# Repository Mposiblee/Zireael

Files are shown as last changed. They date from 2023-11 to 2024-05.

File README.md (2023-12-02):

# Zireael keyboard

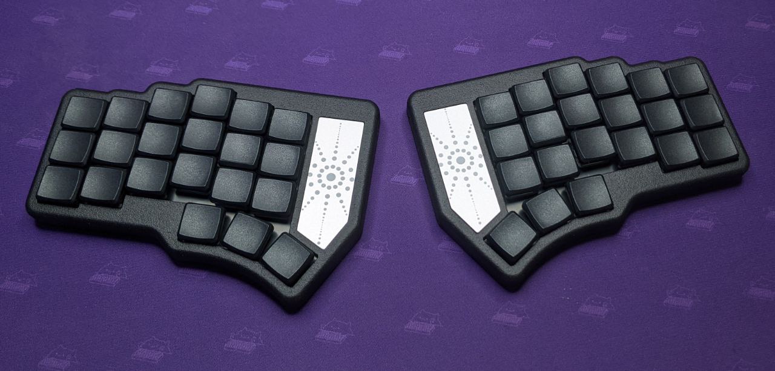
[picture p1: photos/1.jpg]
Dao Shield

Zireael is an ergonomic wireless split keyboard with a design bias. Keyboard for Kailh Choc switches based on MINEW MS88SF2 BLE module.

The keyboard is based on Dao Chok BLE. The locations of components on the board have been changed, space for the battery has been added, and the thumb cluster has also been changed.

Inspiration for the keyboard was taken from these keyboards:
- [Dao chok BLE](https://github.com/yumagulovrn/dao-choc-ble) by [Rafael](https://github.com/yumagulovrn) - components pcb
- [Corne-ish Zen](https://lowprokb.ca/products/corne-ish-zen) by [DarrylDH](https://github.com/LOWPROKB) - the idea to create a beautiful case
- [Cornelius](https://geekhack.org/index.php?topic=109741.0) by [foostan](https://github.com/foostan) - keyboard view

## Features

- Hotswapabble
- ZMK firmware
- Low profile
- Top mount
- Choc Spacing (18mm x 17mm)

## Firmware

Latest compiled ZMK firmware for this keyboard can be found here: https://github.com/Mposiblee/zireael-zmk-config/releases/tag/firmware

Source Code: https://github.com/Mposiblee/zireael-zmk-config

## Build guide

https://github.com/Mposiblee/Zireael/blob/main/doc/build_guide.md

## Contacts

Telegram channel: https://t.me/mposibl

My telegram: https://t.me/mposible

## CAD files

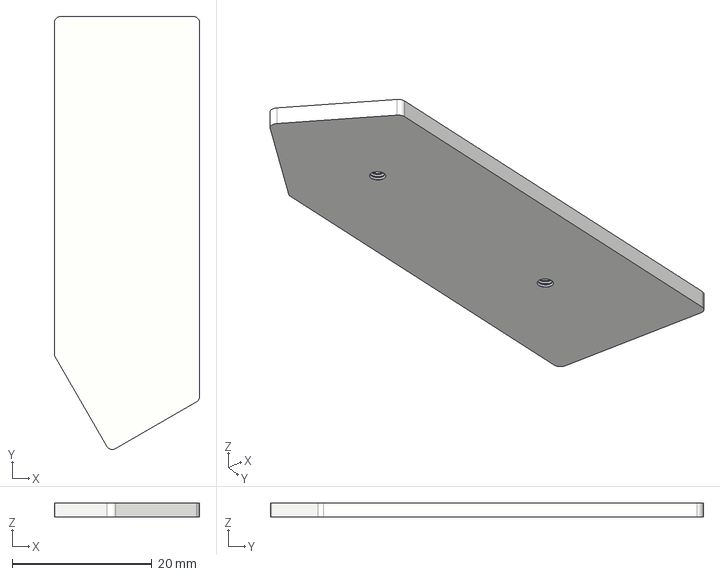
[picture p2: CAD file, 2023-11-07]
case/step/beauty/beauty_right.step
20.8 x 62.0 x 2.00 mm

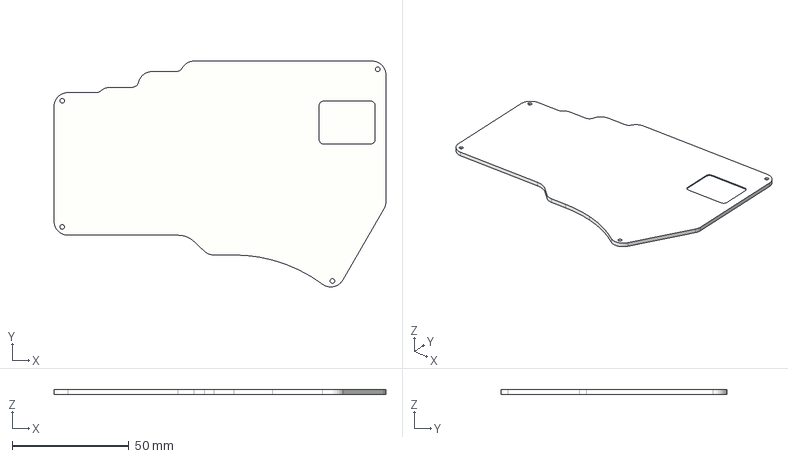
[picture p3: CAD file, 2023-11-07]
case/step/case/bottom_left.step
142.0 x 96.6 x 2.00 mm

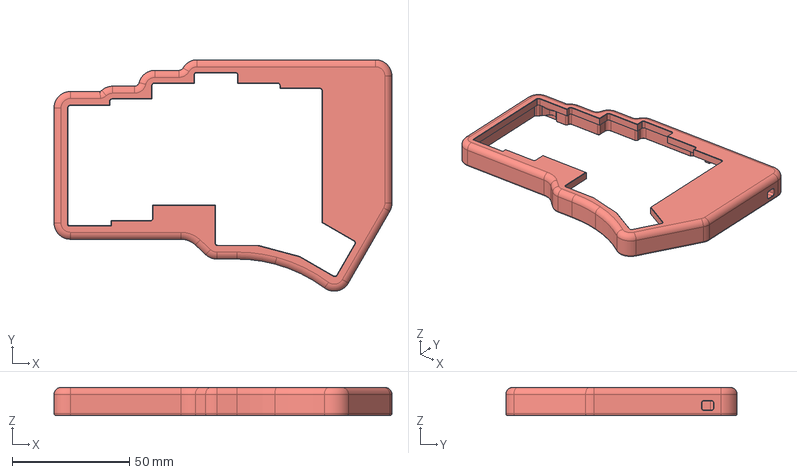
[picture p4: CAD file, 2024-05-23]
case/step/clear/top_left_clear v4.step
144.0 x 98.6 x 12.0 mm

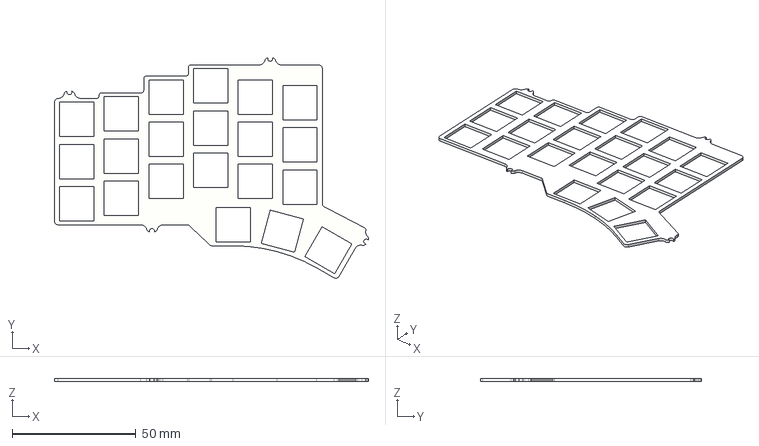
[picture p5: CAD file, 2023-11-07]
case/step/plate/plate.step
126.6 x 88.9 x 1.20 mm

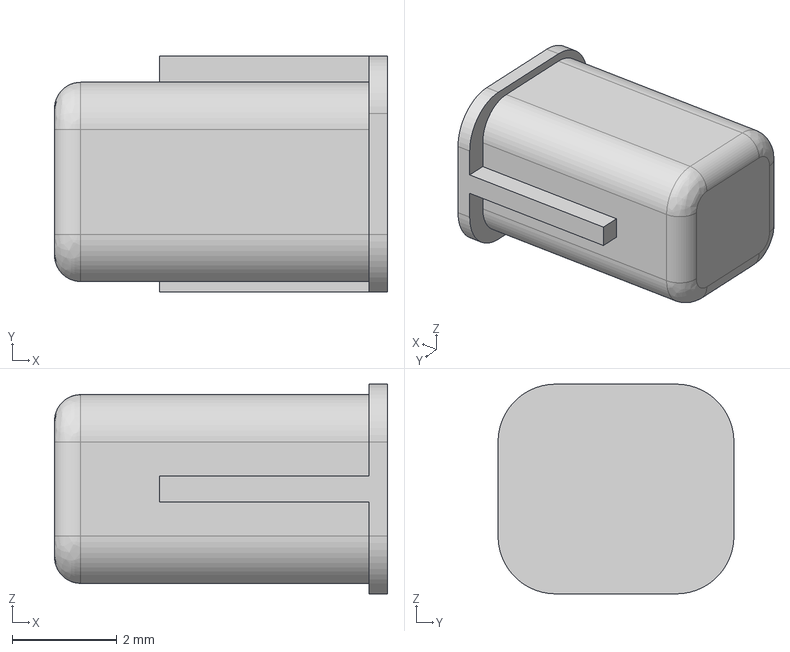
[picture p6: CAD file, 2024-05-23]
case/step/switches/res_button_v2.step
6.35 x 4.50 x 4.00 mm

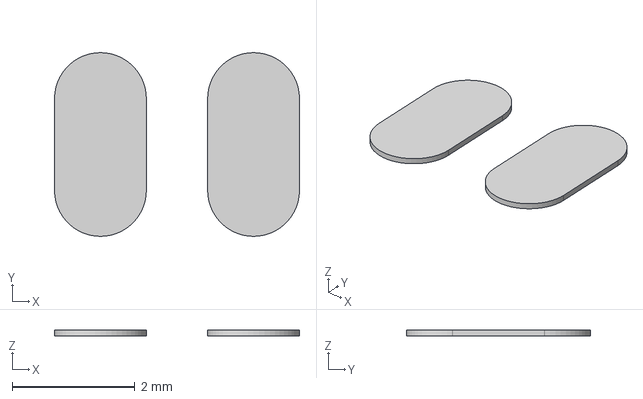
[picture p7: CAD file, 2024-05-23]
kikad/pads.step
4.00 x 3.00 x 0.1 mm

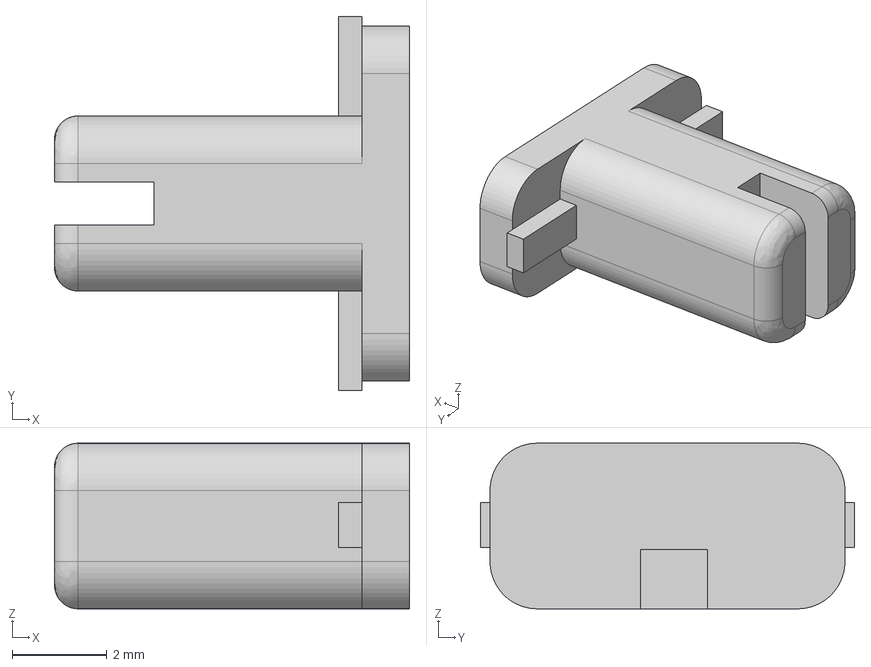
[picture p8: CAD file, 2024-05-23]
case/step/switches/switch_v2.step
7.50 x 7.90 x 3.50 mm

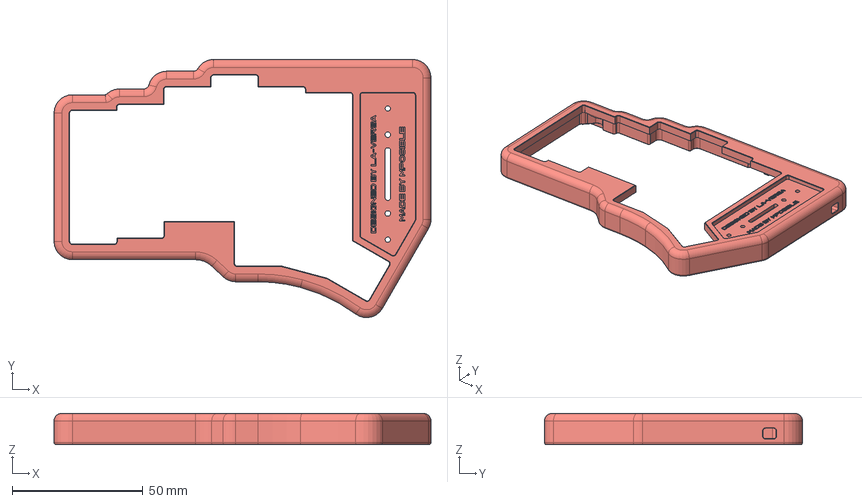
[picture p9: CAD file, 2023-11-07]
case/step/case/top_left.step
144.0 x 98.6 x 12.0 mm

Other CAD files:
case/step/beauty/beauty_left.step
case/step/case/bottom_right.step
case/step/case/top_right.step

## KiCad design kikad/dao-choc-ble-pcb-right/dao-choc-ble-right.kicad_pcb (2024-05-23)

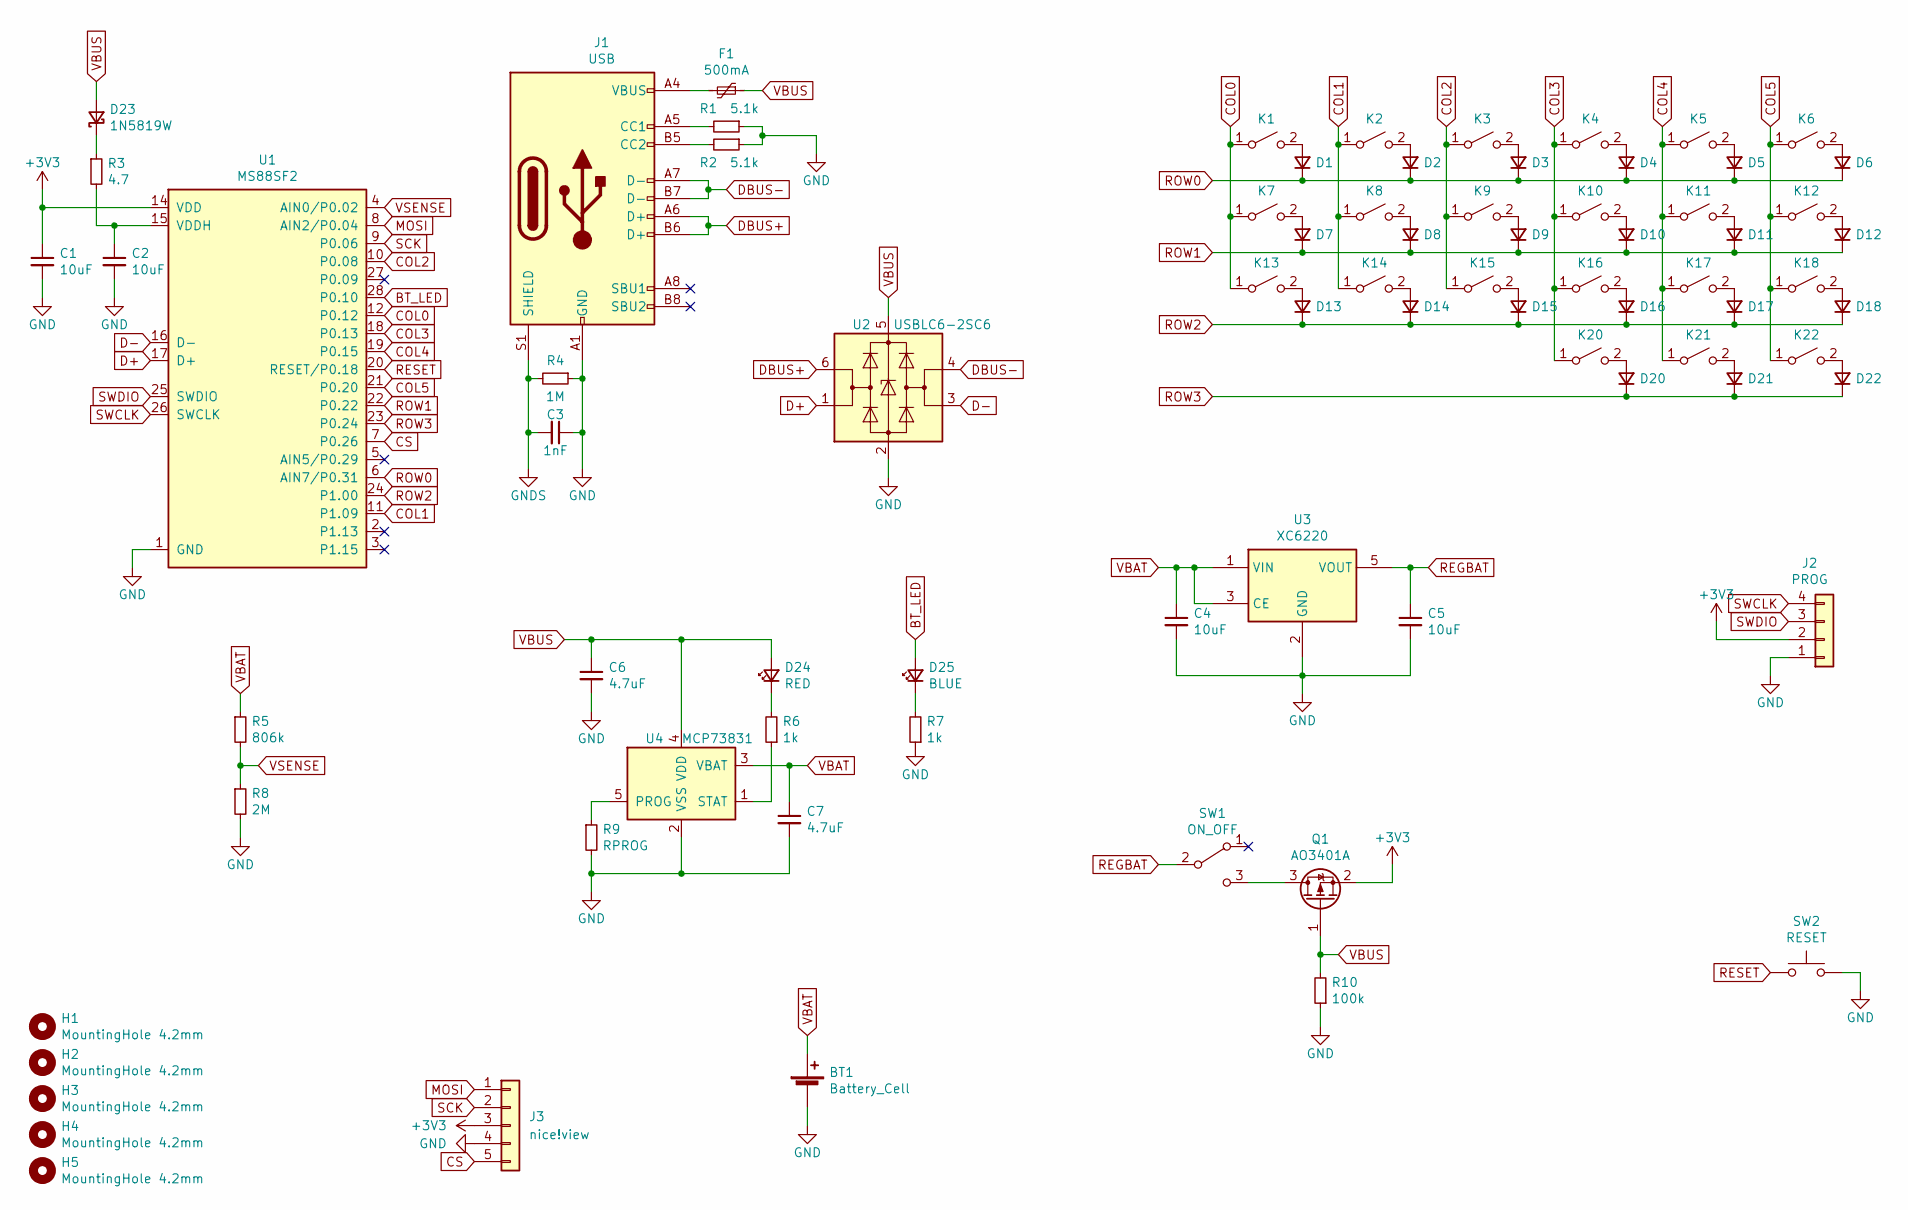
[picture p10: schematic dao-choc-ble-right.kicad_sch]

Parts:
BT1: Battery_Cell; Battery
C1, C2, C4, C5: 10uF; C_0603_1608Metric; LCSC C19702
C3: 1nF; C_0603_1608Metric; LCSC C1588
C6, C7: 4.7uF; C_0603_1608Metric; LCSC C19666
D1, D2, D3, D4, D5, D6, D7, D8, D9, D10, D11, D12, D13, D14, D15, D16, D17, D18, D20, D21, D22: 1N4148WS; D_SOD-323; LCSC C57759
D23: 1N5819W; D_SOD-523; LCSC C169540
D24: RED; LED_0603_1608Metric; LCSC C2286
D25: BLUE; LED_0603_1608Metric; LCSC C72041
F1: 500mA; Fuse_1206_3216Metric; LCSC C355568
H1, H2, H3, H4, H5: MountingHole 4.2mm; Hole_4.2mm
J1: USB; USB-C_C168688; LCSC C168688
J2: PROG
J3: nice!view
K1, K2, K3, K4, K5, K6, K7, K8, K9, K10, K11, K12, K13, K14, K15, K16, K17, K18, K20, K21, K22: KEY_SWITCH; Kailh_PG1350_hotswap
Q1: AO3401A; SOT-23; LCSC C15127
R1, R2: 5.1k; R_0603_1608Metric; LCSC C23186
R3: 4.7; R_0603_1608Metric; LCSC C23164
R4: 1M; R_0603_1608Metric; LCSC C22935
R5: 806k; R_0603_1608Metric; LCSC C103828
R6, R7: 1k; R_0603_1608Metric; LCSC C21190
R8: 2M; R_0603_1608Metric; LCSC C22976
R9: RPROG; R_0603_1608Metric; LCSC C22978
R10: 100k; R_0603_1608Metric; LCSC C25803
SW1: ON_OFF; MSK-12C02; LCSC C431541
SW2: RESET; TS-1086E; LCSC C455276
U1: MS88SF2; MINEW_MS88SF2
U2: USBLC6-2SC6; SOT-23-6; LCSC C558442
U3: XC6220; SOT-23-5; LCSC C86534
U4: MCP73831; SOT-23-5; LCSC C14879

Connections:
+3V3: C1.1, J2.2, J3.3, Q1.2 (S), U1.14 (VDD)
BT_LED: D25.2 (A), U1.28 (P0.10)
COL0: K1.1 (A), K7.1 (A), K13.1 (A), U1.12 (P0.12)
COL1: K2.1 (A), K8.1 (A), K14.1 (A), U1.11 (P1.09)
COL2: K3.1 (A), K9.1 (A), K15.1 (A), U1.10 (P0.08)
COL3: K4.1 (A), K10.1 (A), K16.1 (A), K20.1 (A), U1.18 (P0.13)
COL4: K5.1 (A), K11.1 (A), K17.1 (A), K21.1 (A), U1.19 (P0.15)
COL5: K6.1 (A), K12.1 (A), K18.1 (A), K22.1 (A), U1.21 (P0.20)
CS: J3.5, U1.7 (P0.26)
D+: U1.17 (D+), U2.1 (I/O1)
D-: U1.16 (D-), U2.3 (I/O2)
DBUS+: J1.A6 (D+), J1.B6 (D+), U2.6 (I/O1)
DBUS-: J1.A7 (D-), J1.B7 (D-), U2.4 (I/O2)
GND: BT1.2 (-), C1.2, C2.2, C3.1, C4.2, C5.2, C6.2, C7.2, J1.A1 (GND), J1.A12 (GND), J1.B1 (GND), J1.B12 (GND), J2.1, J3.4, R1.1, R2.1, R4.1, R7.1, R8.2, R9.2, R10.1, SW2.2, U1.1 (GND), U1.13 (GND), U2.2 (GND), U3.2 (GND), U4.2 (VSS)
GNDS: C3.2, J1.S1 (SHIELD), R4.2
MOSI: J3.1, U1.8 (AIN2/P0.04)
unnamed: C2.1, R3.2, U1.15 (VDDH)
unnamed: D1.2 (A), K1.2 (B)
unnamed: D2.2 (A), K2.2 (B)
unnamed: D3.2 (A), K3.2 (B)
unnamed: D4.2 (A), K4.2 (B)
unnamed: D5.2 (A), K5.2 (B)
unnamed: D6.2 (A), K6.2 (B)
unnamed: D7.2 (A), K7.2 (B)
unnamed: D8.2 (A), K8.2 (B)
unnamed: D9.2 (A), K9.2 (B)
unnamed: D10.2 (A), K10.2 (B)
unnamed: D11.2 (A), K11.2 (B)
unnamed: D12.2 (A), K12.2 (B)
unnamed: D13.2 (A), K13.2 (B)
unnamed: D14.2 (A), K14.2 (B)
unnamed: D15.2 (A), K15.2 (B)
unnamed: D16.2 (A), K16.2 (B)
unnamed: D17.2 (A), K17.2 (B)
unnamed: D18.2 (A), K18.2 (B)
unnamed: D20.2 (A), K20.2 (B)
unnamed: D21.2 (A), K21.2 (B)
unnamed: D22.2 (A), K22.2 (B)
unnamed: D23.1 (K), R3.1
unnamed: D24.1 (K), R6.2
unnamed: D25.1 (K), R7.2
unnamed: F1.2, J1.A4 (VBUS), J1.A9 (VBUS), J1.B4 (VBUS), J1.B9 (VBUS)
unnamed: J1.A5 (CC1), R1.2
unnamed: J1.B5 (CC2), R2.2
unnamed: Q1.3 (D), SW1.3 (C)
unnamed: R6.1, U4.1 (STAT)
unnamed: R9.1, U4.5 (PROG)
REGBAT: C5.1, SW1.2 (B), U3.5 (VOUT)
RESET: SW2.1, U1.20 (RESET/P0.18)
ROW0: D1.1 (K), D2.1 (K), D3.1 (K), D4.1 (K), D5.1 (K), D6.1 (K), U1.6 (AIN7/P0.31)
ROW1: D7.1 (K), D8.1 (K), D9.1 (K), D10.1 (K), D11.1 (K), D12.1 (K), U1.22 (P0.22)
ROW2: D13.1 (K), D14.1 (K), D15.1 (K), D16.1 (K), D17.1 (K), D18.1 (K), U1.24 (P1.00)
ROW3: D20.1 (K), D21.1 (K), D22.1 (K), U1.23 (P0.24)
SCK: J3.2, U1.9 (P0.06)
SWCLK: J2.4, U1.26 (SWCLK)
SWDIO: J2.3, U1.25 (SWDIO)
VBAT: BT1.1 (+), C4.1, C7.1, R5.1, U3.1 (VIN), U3.3 (CE), U4.3 (VBAT)
VBUS: C6.1, D23.2 (A), D24.2 (A), F1.1, Q1.1 (G), R10.2, U2.5 (VBUS), U4.4 (VDD)
VSENSE: R5.2, R8.1, U1.4 (AIN0/P0.02)

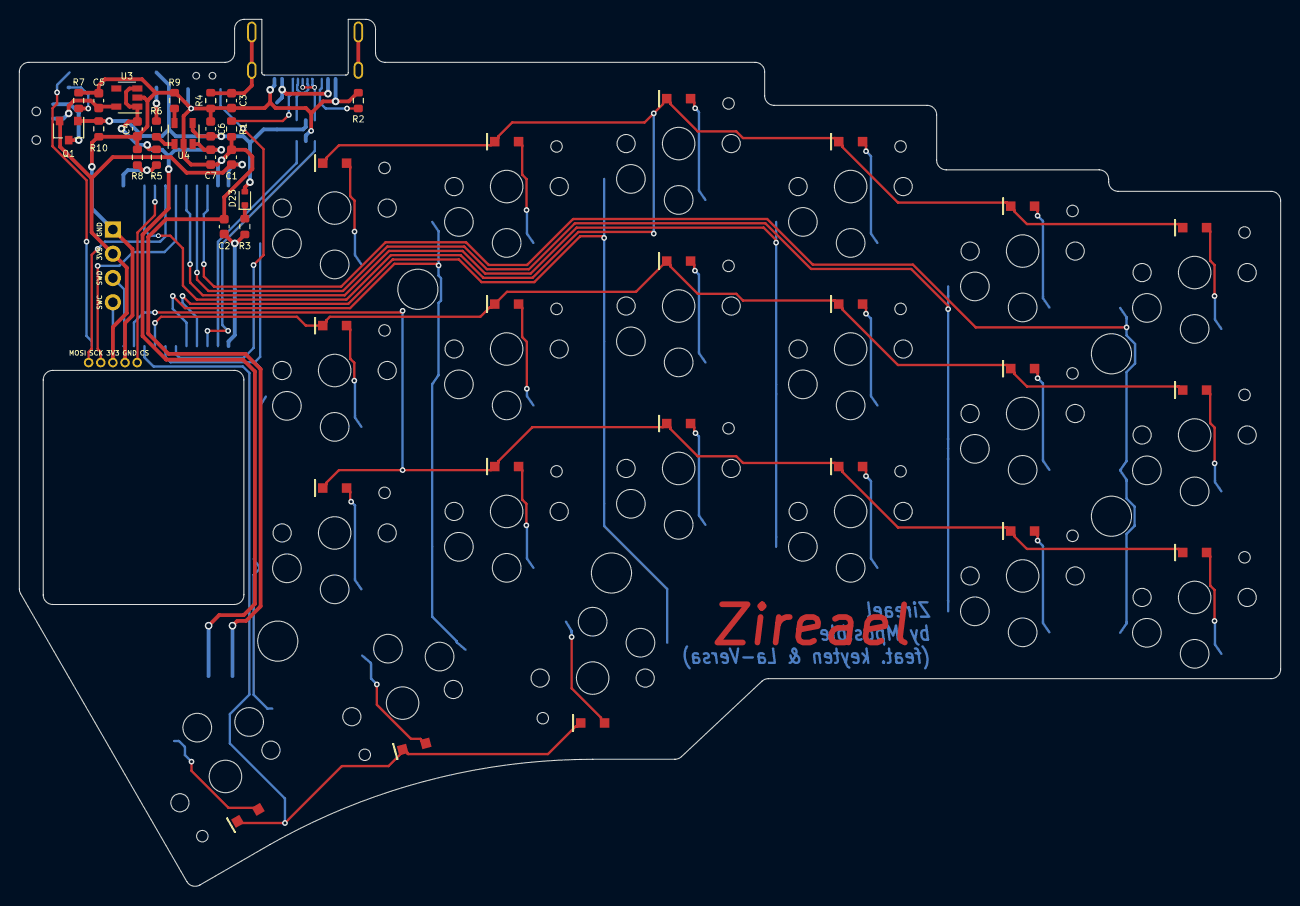
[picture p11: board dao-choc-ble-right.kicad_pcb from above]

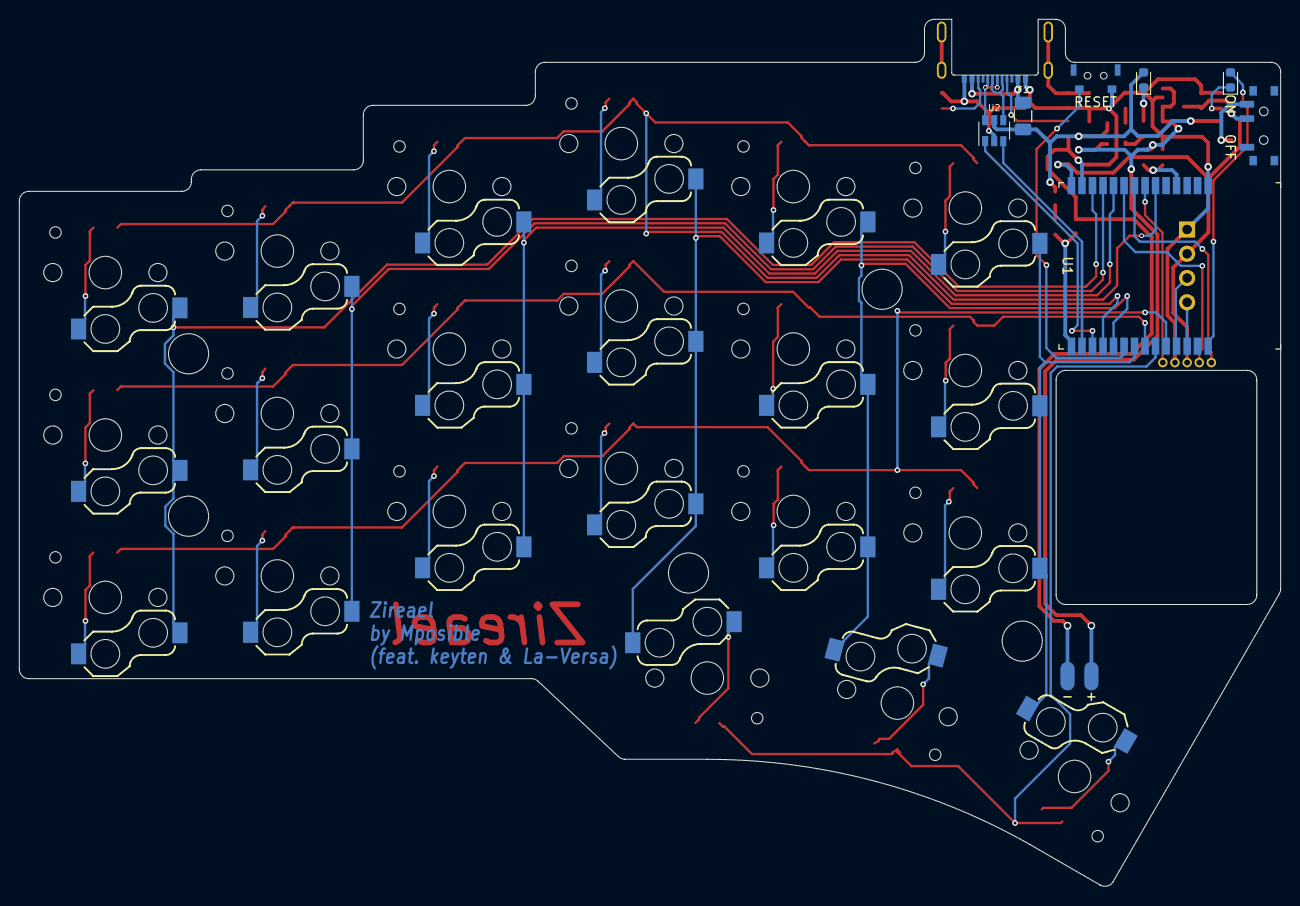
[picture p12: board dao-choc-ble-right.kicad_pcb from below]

Board: 2 copper layers, 132.0 x 90.7 mm, 79 parts (9 on the bottom side), 59 nets.

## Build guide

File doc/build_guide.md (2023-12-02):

## Build Guide

## Order PCB

You can download the latest version production files from [here](https://github.com/Mposiblee/Zireael/releases/tag/Gerbers)

All files are uploaded to the [JLCPCB](https://jlcpcb.com/) without any problems, you can also order from other pcb production factories.
 - PCB Thickness 1.2mm
 - Plate Thickness 1.2mm
 - 2 layers
 - You can order an smt assembly, BOM and POS are in [gerbers](https://github.com/Mposiblee/Zireael/releases/tag/Gerbers)

## BOM

| Reference | Name | Package  | Value | AliExpress | LCSC | Qty |
|---|---|---|---|---|---|-----|
| C1-C2, C4-C5 | Capacitor | 0603 | 10uF | [10uF - 100 pcs](https://aliexpress.com/item/32966526545.html?sku_id=66569661174) | C19702  | 8 |
| C3 | Capacitor | 0603 | 1nF | [1nF - 100 pcs](https://aliexpress.com/item/32966526545.html?sku_id=66569661147) | C1588 | 2 |
| C6-C7 | Capacitor | 0603 | 4.7uF | [4.7uF 100 pcs](https://aliexpress.com/item/32966526545.html?sku_id=66569661173) | C19666  | 4 |
| D1-D22 | Diode | SOD-323  | 1N4148WS | [1N4148WS SOD-323 - 100 pcs](https://aliexpress.com/item/32849879904.html?sku_id=65195962305) | C57759  | 44  |
| D23 | Diode | SOD-523  | 1N5819W | [1N5819W SOD-523 - 100 pcs](https://aliexpress.ru/item/32849879904.html) | С5185918| 2 |
| D24 | LED | 0603 | RED | [0603 RED - 100 pcs](https://aliexpress.com/item/1206456185.html?sku_id=65106628406) | C2286 | 2 |
| D25 | LED | 0603 | BLUE | [0603 BLUE - 100 pcs](https://aliexpress.com/item/1206456185.html?sku_id=65106628409) | C72041  | 2 |
| F1 | Fuse | 1206 | 500mA | [1206 500mA - 50 pcs](https://aliexpress.com/item/32907456681.html?sku_id=12000033093354867) | C355568 | 2 |
| J1 | USB Receptacle | ? | ? | [1.6mm - 10 pcs](https://aliexpress.com/item/32998900371.html?sku_id=12000021526913497) [0.8mm - 10 pcs](https://aliexpress.com/item/32998900371.html?sku_id=12000021526913496) | C168688 | 2 |
| K1-K22 | Kailh Choc Hotswap Socket | ? | ? | [90 pcs](https://aliexpress.com/item/33023283633.html?sku_id=10000000883911874) | ? | 44  |
| Q1 | P-Mosfet | SOT-23 | AO3401A | [50 pcs](https://aliexpress.com/item/32990534792.html) | C15127  | 2 |
| R1-R2 | Resistor | 0603 | 5.1k | [5.1K - 100 pcs](https://aliexpress.com/item/1005001436923851.html?sku_id=12000016109475028) | C23186  | 4 |
| R3 | Resistor | 0603 | 4.7 | [4.7R - 100 pcs](https://aliexpress.com/item/1005001436923851.html?sku_id=12000016109357956) | C23164  | 2 |
| R4 | Resistor | 0603 | 1M | [1M - 100 pcs](https://aliexpress.com/item/1005001436923851.html?sku_id=12000016109475082) | C22935  | 2 |
| R5 | Resistor | 0603 | **806k*** | [820K - 100pcs](https://aliexpress.com/item/1005001436923851.html?sku_id=12000016109475080) | C103828 | 2 |
| R6-R7 | Resistor | 0603 | 1k | [1K - 100pcs](https://aliexpress.com/item/1005001436923851.html?sku_id=12000016109475011) | C21190  | 4 |
| R8 | Resistor | 0603 | 2M | [2M - 100pcs](https://aliexpress.com/item/1005001436923851.html?sku_id=12000016109475089) | C22976  | 2 |
| R9 | Resistor | 0603 | **RPROG**** | [3.3K - 100pcs](https://aliexpress.com/item/1005001436923851.html?sku_id=12000016109475023) | C22978  | 2 |
| R10 | Resistor | 0603 | 100k | [100K - 100pcs](https://aliexpress.com/item/1005001436923851.html?sku_id=12000016109475058) | C25803  | 2 |
| SW1 | SPDT Switch | ? | MSK-12C02 | [50 pcs](https://aliexpress.com/item/4000685483225.html?sku_id=12000020983019153) | C431541 | 2 |
| SW2 | Tactile Button | ? | TS-1086E | [100 pcs](https://aliexpress.com/item/1005001846404680.html) | C455276 | 2 |
| U1 | MCU | ? | MINEW MS88SF2 | [1 pcs](https://aliexpress.com/item/4000101935456.html) | ? | 2 |
| U2 | ESD Protection IC | SOT-23-6 | USBLC6-2SC6 | [USBLC6-2SC6 - 10 pcs](https://aliexpress.com/item/32523780535.html?sku_id=12000027513378590) | C558442 | 2 |
| U3 | Voltage Regulator IC | SOT-23-5 | XC6220 | [30 pcs](https://aliexpress.com/item/4000271612572.html) | C86534  | 2 |
| U4 | Battery Charging IC | SOT-23-5 | MCP73831 | [10 pcs](https://aliexpress.com/item/32714249253.html) | C14879  | 2 |

**806k*** You can replace it with 820k resistor, but voltage sensing circuit (for battery status) will give somewhat invalid values

**RPROG**** Value depends on your battery capacity. For 300mAh battery should be 3.3K

### Other hardware

| Name | Qty  | AliExpress |
|---|---|---|
| LiPo Battery 502020 | 2 | [Global - 2 pcs](https://aliexpress.ru/item/1005004771463980.html) [RU - 1 pcs](https://www.chipdip.ru/product/robiton-lp502020) |
| Insert screw | 16 | [M2(OD3.5mm) L 2mm](https://aliexpress.ru/item/1005006261832275.html) | 
| Screw | 16 | [Black M2x4mm - 50 pcs](https://aliexpress.com/item/32806166548.html?sku_id=66702152887) |
| Screw | 4 | [Black M2x3mm - 50 pcs](https://aliexpress.ru/item/32806166548.html?sku_id=66702152877) |
| Silicone Bumpers | 8-10 | [100 pcs](https://aliexpress.com/item/32912066603.html) |

## Assemble your case

### First, you need to solder the screw insert with a soldering iron.



### Next, put the shield and tighten it.




### Insert all the switches into the plate.



### After that, insert the switches plate plate into the pcb.



### Put the switches in the case.



### Place the pcb carefully in the case, placing the power button on top, and also monitor the location of the type c port.



###  First, tighten all the screws by half. After making sure that the pcb is positioned exactly, tighten all the screws to the end.



### Close the bottom and tighten the screws.



### The case is assembled



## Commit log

2023-11-07 Create stl
2023-11-07 Update and rename bottom_left.step to bottom_left.step
    [bottom_left.step]
2023-12-02 Create switches
2024-01-06 The dimensions have been slightly changed
    [switch_button.step]
2024-03-12 add zireael clear case
    [top_left_clear.step, top_right_clear.step]
2024-05-23 New version clear case
    [top_left_clear v4.step]
2024-05-23 New versions switches
    [res_button_v2.step, switch_v2.step]
